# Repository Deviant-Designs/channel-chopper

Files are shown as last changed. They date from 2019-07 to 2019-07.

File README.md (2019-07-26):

# Channel-Chopper
A Fire button for any estim device. Perfect for BDSM play 

## Quick Disclaimer
I am neither an electrical engineer or a software developer. I made this for fun. There are probably many many flaws in this. But that being said, it works and works well for what I want. I don't mind constructive critiscm at all (actually I'll be greatful for it) but please be nice with it. It sucks when you put lots of effort into something and people just hammer it for its flaws :)

## What is it
this is a inline controller to turn on and off estim signals. You attach it between the estim unit and the bipolar electrode. it has 4 buttons on it which when depressed allow the estim signals to passthrough to the electrodes. It also works via serial comunication so you can link it up to other equipment if you wish. 

## You said 4 Channels, Why 5 inputs/Outputs?
channel 5 in the channel chopper is actually controlled by channel 4. the idea behind this is if you have 2 bipolar nipple clamps. One on each nipple. If you press the channel 4 button they will both fire at the same time

## BOM
11 - 3.5mm Panel Mount Stereo Jacks

10 - MOC 3023

1 - Arduino Pro Micro (it has to be micro not mini for this PCB)

14 - 220Ω Resistors

4 - 5mm LEDS

4 - Buttons/swtiches

## Serial Format
This is done through the USB cable. Basic serial comunication at 9600. The format is as follows

`shock¬"channel"¬"state"`

There are 4 channels and the states are either `1` for on or `0` for off. So if we wanted to turn channel 2 on we would send

`shock¬2¬1`

and if we wanted to turn channel 2 off it would be 

`shock¬2¬0`

## why is there another serial connection linked to a 3.5mm jack
this hasn't been implemented in software yet, but I put this there in case I wanted to setup software serial to control the box from another arduino. or maybe use this box to trigger other devices. The tip is connected to pin A1 and the ring to A0

## Thankyou's 
I need to say thanks to both Georgexx and Onwrikbaar as they showed me the light with the MOC3023's

## Links
[Discord](https://discord.gg/6kjEPdq)

If you like what we do and want to support us then please consider the following options

[Patreon](https://www.patreon.com/deviantdesigns)

[Ko-Fi - if you'd rather a one off donation](https://www.Ko-fi.com/deviantdesigns)

[Twitter - sharing our work helps lots too if you can't afford to support financially](https://twitter.com/_DeviantDesigns)

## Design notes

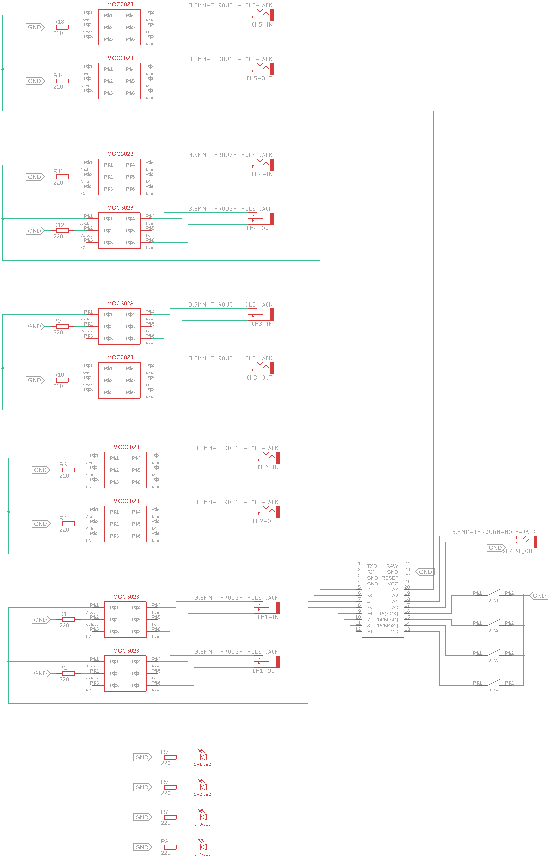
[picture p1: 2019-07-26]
Schematic.png

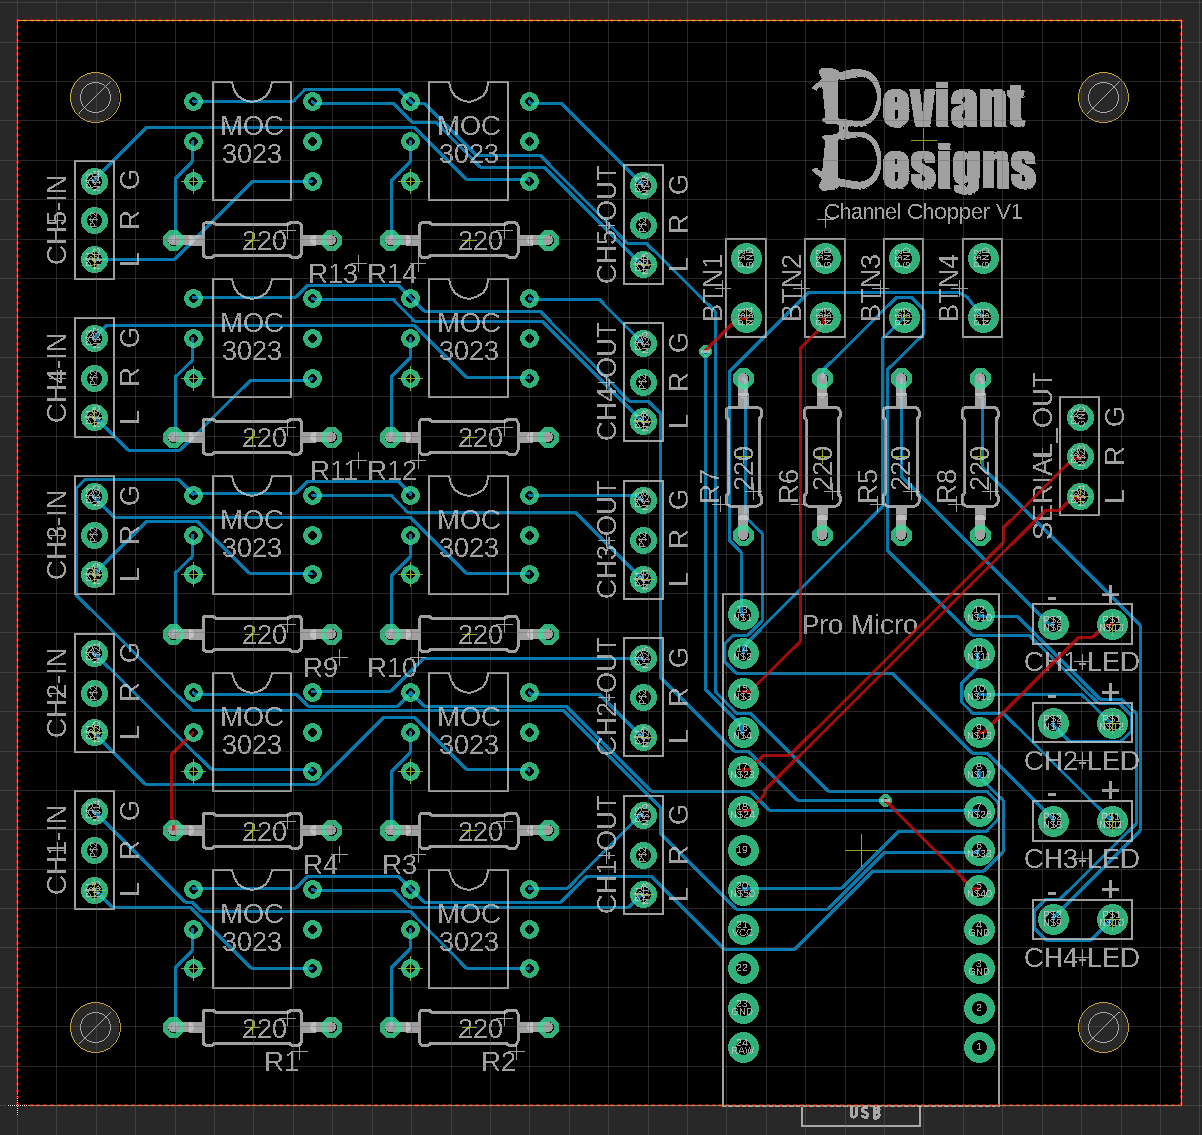
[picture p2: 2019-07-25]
Channel Chopper V1.png

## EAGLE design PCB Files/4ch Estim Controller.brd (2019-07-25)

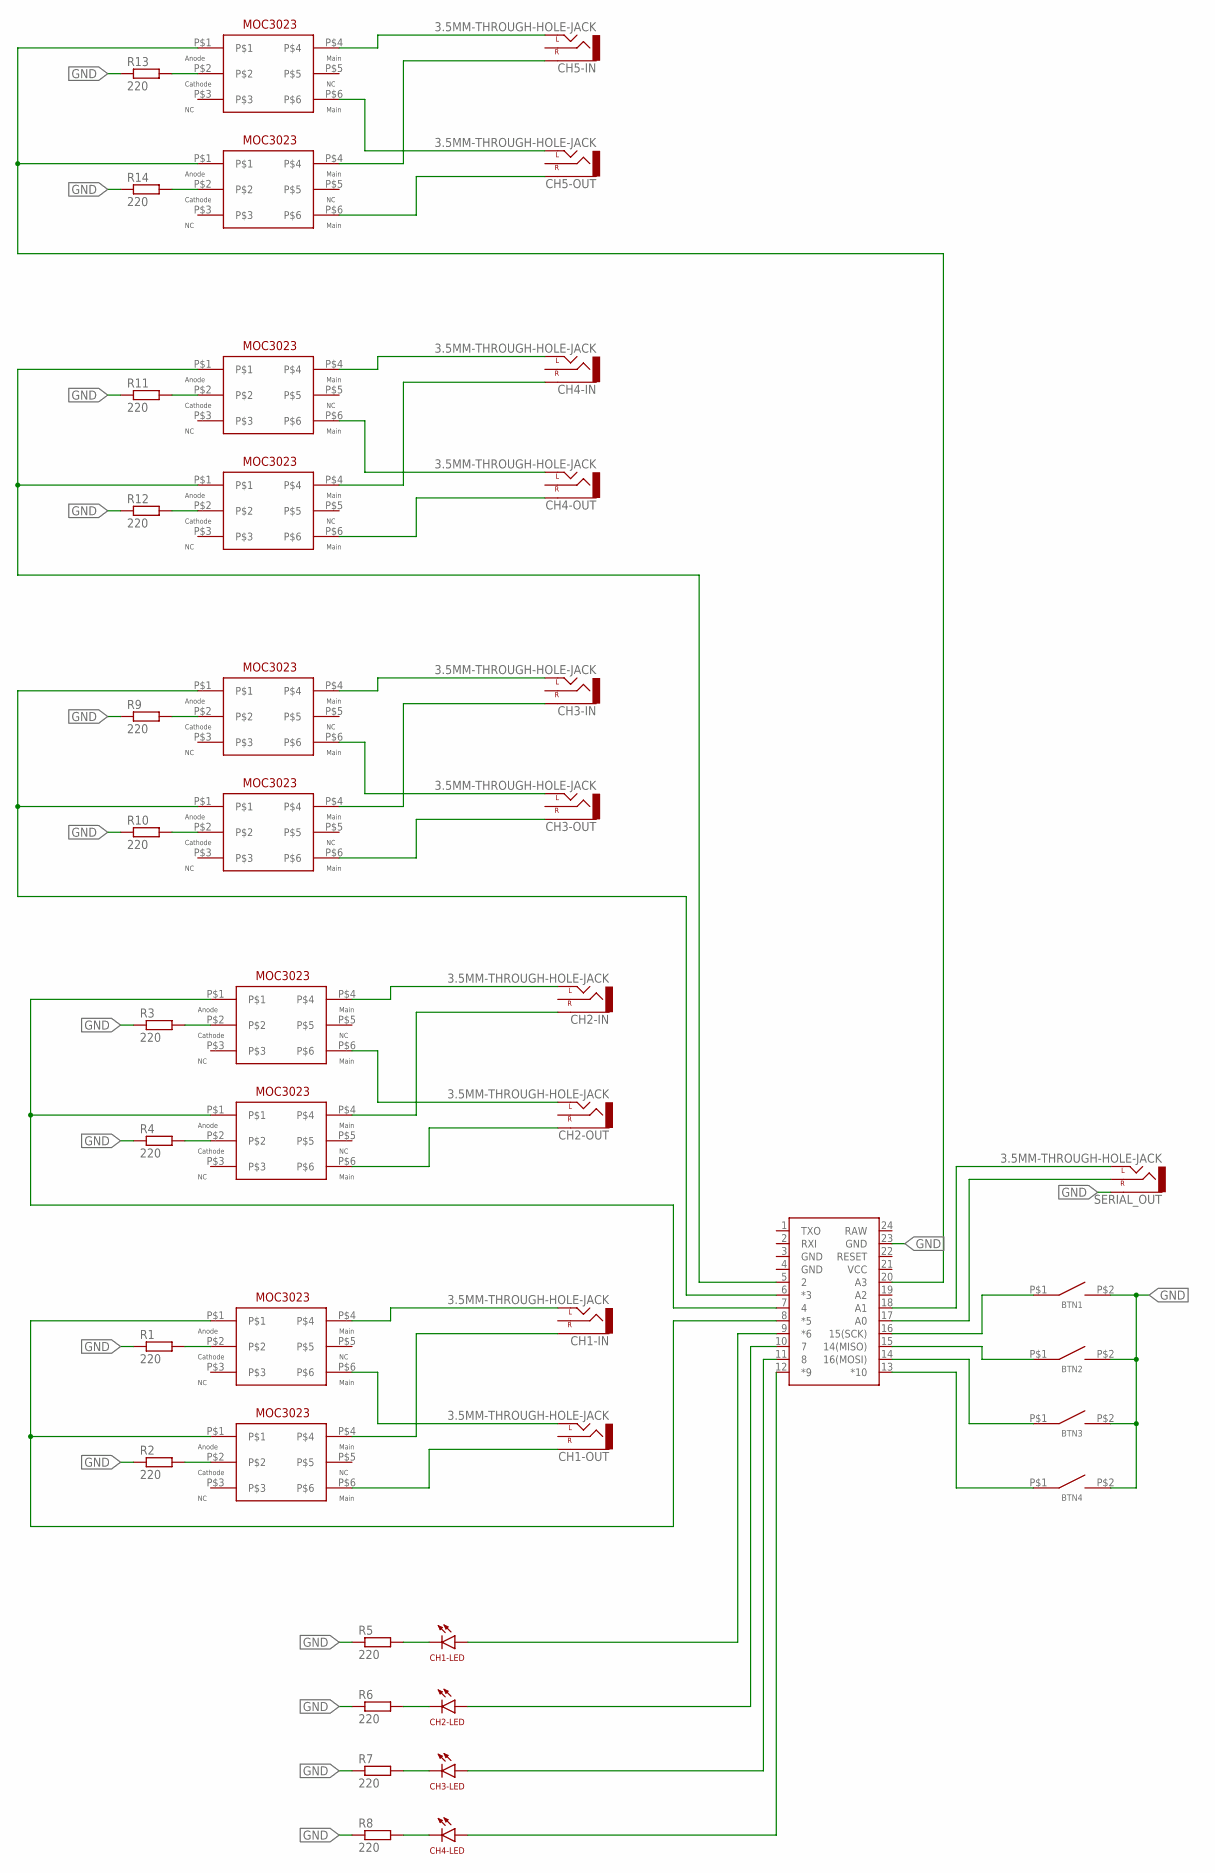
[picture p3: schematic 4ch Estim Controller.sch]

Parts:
B1: PRO_MICRO
BTN1, BTN2, BTN3, BTN4: THROUGH-HOLE-SWITCH
CH1-IN, CH1-OUT, CH2-IN, CH2-OUT, CH3-IN, CH3-OUT, CH4-IN, CH4-OUT, CH5-IN, CH5-OUT: 3.5MM-THROUGH-HOLE-JACK; THROUGH-HOLE-JACK
CH1-LED, CH2-LED, CH3-LED, CH4-LED: THROUGH-HOLE-LED
R1, R2, R3, R4, R5, R6, R7, R8, R9, R10, R11, R12, R13, R14: 220; 0207/10
SERIAL_OUT: 3.5MM-THROUGH-HOLE-JACK; THROUGH-HOLE-JACK
U$1, U$2, U$3, U$4, U$9, U$10, U$11, U$12, U$13, U$14: MOC3023

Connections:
GND: B1.3 (GND), B1.4 (GND), B1.23 (GND), BTN1.P$2, BTN2.P$2, BTN3.P$2, BTN4.P$2, R1.1, R2.1, R3.1, R4.1, R5.1, R6.1, R7.1, R8.1, R9.1, R10.1, R11.1, R12.1, R13.1, R14.1, SERIAL_OUT.P$3 (SLEEVE)
unnamed: B1.13 (*10), BTN4.P$1
unnamed: B1.14 (16(MOSI)), BTN3.P$1
unnamed: B1.15 (14(MISO)), BTN2.P$1
unnamed: B1.16 (15(SCK)), BTN1.P$1
unnamed: CH1-IN.P$1 (LEFT), U$3.P$4
unnamed: CH1-LED.P$2 (C), R5.2
unnamed: CH2-LED.P$2 (C), R6.2
unnamed: CH3-LED.P$2 (C), R7.2
unnamed: CH4-LED.P$2 (C), R8.2
unnamed: B1.12 (*9), CH4-LED.P$1 (A)
unnamed: B1.11 (8), CH3-LED.P$1 (A)
unnamed: B1.10 (7), CH2-LED.P$1 (A)
unnamed: B1.9 (*6), CH1-LED.P$1 (A)
unnamed: CH1-IN.P$3 (SLEEVE), U$4.P$4
unnamed: R2.2, U$4.P$2
unnamed: R1.2, U$3.P$2
unnamed: B1.8 (*5), U$3.P$1, U$4.P$1
unnamed: CH1-OUT.P$1 (LEFT), U$3.P$6
unnamed: CH1-OUT.P$3 (SLEEVE), U$4.P$6
unnamed: CH2-IN.P$1 (LEFT), U$1.P$4
unnamed: CH2-IN.P$3 (SLEEVE), U$2.P$4
unnamed: CH2-OUT.P$1 (LEFT), U$1.P$6
unnamed: B1.17 (A0), SERIAL_OUT.P$2 (RIGHT)
unnamed: B1.18 (A1), SERIAL_OUT.P$1 (LEFT)
unnamed: CH2-OUT.P$3 (SLEEVE), U$2.P$6
unnamed: B1.7 (4), U$1.P$1, U$2.P$1
unnamed: R4.2, U$2.P$2
unnamed: R3.2, U$1.P$2
unnamed: CH3-IN.P$1 (LEFT), U$9.P$4
unnamed: CH3-IN.P$3 (SLEEVE), U$10.P$4
unnamed: CH3-OUT.P$1 (LEFT), U$9.P$6
unnamed: CH3-OUT.P$3 (SLEEVE), U$10.P$6
unnamed: B1.6 (*3), U$9.P$1, U$10.P$1
unnamed: R9.2, U$9.P$2
unnamed: R10.2, U$10.P$2
unnamed: CH4-IN.P$1 (LEFT), U$11.P$4
unnamed: CH4-IN.P$3 (SLEEVE), U$12.P$4
unnamed: CH4-OUT.P$1 (LEFT), U$11.P$6
unnamed: CH4-OUT.P$3 (SLEEVE), U$12.P$6
unnamed: B1.5 (2), U$11.P$1, U$12.P$1
unnamed: R11.2, U$11.P$2
unnamed: R12.2, U$12.P$2
unnamed: CH5-IN.P$1 (LEFT), U$13.P$4
unnamed: CH5-IN.P$3 (SLEEVE), U$14.P$4
unnamed: CH5-OUT.P$1 (LEFT), U$13.P$6
unnamed: CH5-OUT.P$3 (SLEEVE), U$14.P$6
unnamed: R13.2, U$13.P$2
unnamed: R14.2, U$14.P$2
unnamed: B1.20 (A3), U$13.P$1, U$14.P$1
RAW: B1.24 (RAW)
VCC: B1.21 (VCC)

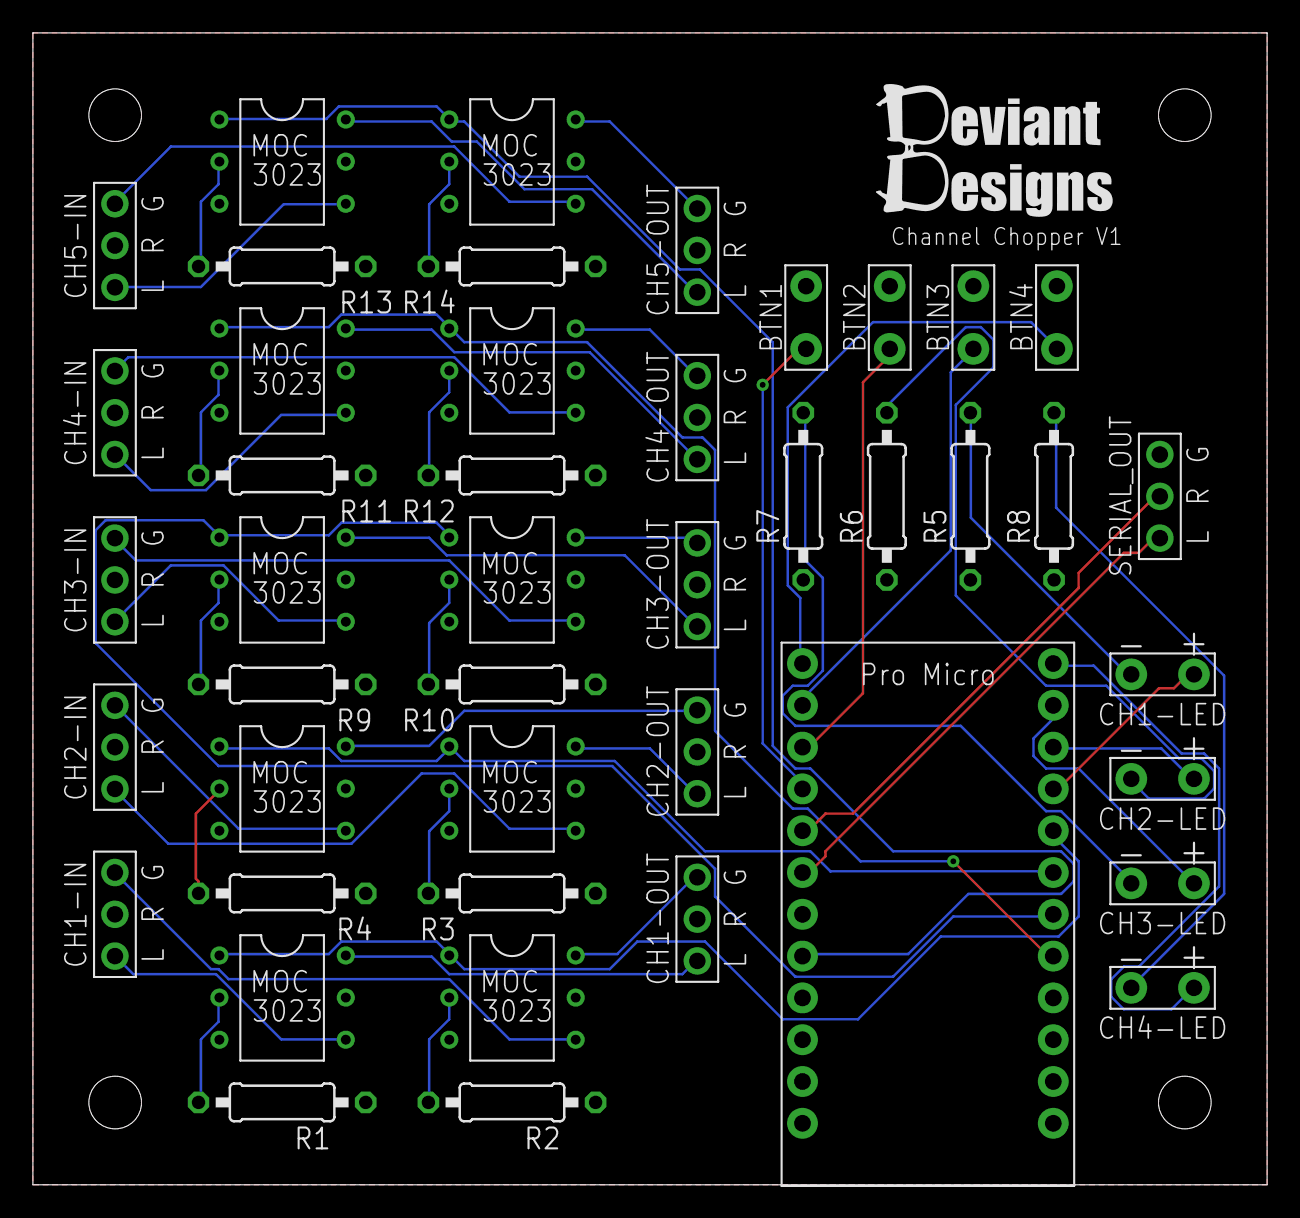
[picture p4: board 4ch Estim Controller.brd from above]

Board: 2 copper layers, 75.0 x 70.0 mm, 45 parts (0 on the bottom side), 50 nets.

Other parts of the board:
U$15: LOGO_DD_10MM_HIGH

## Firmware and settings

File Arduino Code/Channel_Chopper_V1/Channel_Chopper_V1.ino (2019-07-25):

// recieved message will be "Shock¬1¬1" this equates to channel 1, turn on


const byte numChars = 32;
char receivedChars[numChars]; // an array to store the received data

boolean newData = false;

char message1FromPC[32] = {0};
char message2FromPC[32] = {0};
char message3FromPC[32] = {0};

char recvChar;
char endMarker = '\n';

int shockChannelPinArray[] = {6,7,8,9}; //holds the pins for the LED channel outputs
int shockChannelPinArray2[] = {5,4,3,2,A3}; //holds the pins for the octocouplers ADD A3 WHEN WORKING!!!!!!!!!!!!!!!!!!!!!!!!!!!!!!!!!!!!!!!!!!!!!!!!!
int buttonChannelPinArray[] = {15,14,16,10}; //CHANGE THIS TO MATCH BUTTON PINS!!!!!!!!!!!!!

int shockChannelActive[] = {0,0,0,0};
int buttonShockChannelActive[] = {0,0,0,0};

void setup() {
 Serial.begin(9600);
 Serial.println("<Arduino is ready>");
 for (int i = 0; i<(sizeof(shockChannelPinArray)/sizeof(shockChannelPinArray[0])); i++) {
  pinMode(shockChannelPinArray[i], OUTPUT);
 } 
 for (int i = 0; i<4; i++) {
  pinMode(shockChannelPinArray2[i], OUTPUT);
  pinMode(buttonChannelPinArray[i], INPUT_PULLUP);
 }
 pinMode(shockChannelPinArray2[4], OUTPUT);
}

void loop() {
 recvWithEndMarker();
 showNewData();
buttonPress();
 serialDebug();
 actualShock();  ///////////////////////////////////////////////////////////////////////////////////////////////////////////////////////////////////////////////////////
}

void serialDebug() {
  Serial.print ("Shock Channel Active Array - ");
  for (int i = 0; i<=(sizeof(buttonChannelPinArray) / sizeof(shockChannelPinArray[0]))-1; i++){
    Serial.print("[");
  Serial.print (shockChannelActive[i]);
  Serial.print("]");
  }
  Serial.println("");
  Serial.print ("Button Channel Active Array - ");
  for (int i = 0; i<=(sizeof(buttonChannelPinArray) / sizeof(buttonChannelPinArray[0]))-1; i++){
    Serial.print("[");
    Serial.print (buttonShockChannelActive[i]);
    Serial.print("]");
  }
  Serial.println("");
}

//This func recieves the incoming serial data and adds it to a Char array. 
//when end marker is recieved it sets newdata flag to true
void recvWithEndMarker() {
 static byte ndx = 0;
 char endMarker = '\n';
 char rc;

 // if (Serial.available() > 0) {
   while (Serial.available() > 0 && newData == false) {
    rc = Serial.read();
    if (rc != endMarker) {
      receivedChars[ndx] = rc;
      ndx++;
      if (ndx >= numChars) {
        ndx = numChars - 1;
      }
    }
    else {
      receivedChars[ndx] = '\0'; // terminate the string
      ndx = 0;
      newData = true;
      }
  }
}


//if newData flag is triggered then parse the data
void showNewData() {
  if (newData == true) {
//  Serial.print("This just in ... ");
//  Serial.println(receivedChars);
  newData = false;
  parseData();
//  showParsedData();
   shock();
  }
}

void parseData() {

    // split the data into its parts

  char * strtokIndx; // this is used by strtok() as an index

  strtokIndx = strtok(receivedChars,"¬");      // get the first part - the string
  strcpy(message1FromPC, strtokIndx); // copy it to messageFromPC
  strtokIndx = strtok(NULL,"¬");      // get the first part - the string
  strcpy(message2FromPC, strtokIndx); // copy it to messageFromPC
  strtokIndx = strtok(NULL,"¬");      // get the first part - the string
  strcpy(message3FromPC, strtokIndx); // copy it to messageFromPC
 // strtokIndx = strtok(NULL, ","); // this continues where the previous call left off
 // integerFromPC = atoi(strtokIndx);     // convert this part to an integer
  // strtokIndx = strtok(NULL, ",");
  // floatFromPC = atof(strtokIndx);     // convert this part to a float

}

void shock() {
//  Serial.println("shock func running");
  if (strcmp(message1FromPC,"shock")==0) {
  int integer1FromPC = atoi(message2FromPC)-1; //convert string to int. Channels coming in would be 1-4, make 0-3
  int integer2FromPC = atoi(message3FromPC);
  
    if (integer1FromPC >= 0 && integer1FromPC < 4) {
    shockChannelActive[integer1FromPC] = integer2FromPC;  ////////////////////////////////////////////////////////////////////////////////////////////////////////////////
  }

}
}

void buttonPress() {
  //Serial.print(sizeof(buttonChannelPinArray) / sizeof(shockChannelPinArray[0]));
  for (int i = 0; i<4; i++) {
    if (digitalRead(buttonChannelPinArray[i])==LOW) {
      buttonShockChannelActive[i] = 1;
    } else {
      buttonShockChannelActive[i] = 0;
    }
  }
  //Serial.print ("Button Shock - ");

 // Serial.println("");
}

void actualShock() {   /////////////////////////////////////////////////////////////////////////////////////////////////////////////////////////////////////////////////////
 for (int i = 0; i<4; i++) {
   if (buttonShockChannelActive[i] == 1 || shockChannelActive[i] == 1) {
     digitalWrite(shockChannelPinArray[i], HIGH);
     digitalWrite(shockChannelPinArray2[i], HIGH);
     if (buttonShockChannelActive[3] == 1 || shockChannelActive[3] == 1) {
      digitalWrite(shockChannelPinArray2[4], HIGH);
     }
   }  else {
   digitalWrite(shockChannelPinArray[i], LOW);
   digitalWrite(shockChannelPinArray2[i], LOW);
       if (buttonShockChannelActive[3] == 0 || shockChannelActive[3] == 0) {
      digitalWrite(shockChannelPinArray2[4], LOW);
     }
 }
}
}
